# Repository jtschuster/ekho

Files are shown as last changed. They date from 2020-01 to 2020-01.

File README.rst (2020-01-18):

Ekho
====

This repository contains the hardware, firware and tools required to run the Ekho.

This version of the hardware is designed by Jacob Sorber and Arwa Alsubhi from PERSIST Lab at Clemson University. Tools and firmware are adapted from their original design and are significantly upgraded by Abu Bakar and Jackson Schuster from KaMoaMoa Lab at Northwestern University. 

Tool Requirements
-----------------
- GNU Scientific Library (GSL) 
- OpenGL Utility Kit (GLUT)
- g++ and gcc
- Arduino and Teensyduino
- Make
- GNUplot
- EAGLE

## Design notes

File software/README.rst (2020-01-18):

Ekho Software
=============

This directory contains firmwares and tools required to run the Ekho

Sub-Directories
---------------

- ``pc_recorder`` Teensy firmware and a real-time processing code to record IV surfaces while connected to a computer. Includes a real-time plot of the IV curves.
- ``mobile_recorder`` Teensy firmware to record IV surfaces when disconnected from a computer (for recording in the wild), and code to convert the recorded data to useable formats.
- ``pc_emulator`` Computer and teensy code to emulate a recorded IV surface.
- ``tools`` Tools for visualizing and converting binary data to other readable formats.

File Formats
------------

**.raw**
    *Raw* format is what the recorded data is placed into after initial processing. The data is in binary format and can be converted into a text file using the tools in pc_recorder. It has the following format repeated for a number of timestamps:
    
    ``<timestamp, 1 double value> <voltages, 512 long double values> <currents, 512 long double values>``

    The j'th voltage value corresponds to the j'th current value. Together, the 512 (voltage, current) points can be regressed to create an IV curve. 

**.sdr**
    *SDRaw* format is used by mobile_recorder to store recorded data in the SD card in a simpler form compared to ``.raw`` format. This is done because of the optimizations that are made to avoid floating point operatins on Teensy so to make the processing faster on the mobile platform. It has the following format repeated for a number of timestamps:
    
    ``<timestamp, 4 bytes> <raw values, 10 bytes>``

**.ivs** 
    *IV surface* format is used by pc_emulator and is generated after finding a regression on the raw data points. The regression coverts 512 raw data points per IV curve from ``.raw`` file into 65 data points. This makes emulation process faster. Several 65-point IV curves together make an IV surface (``.ivs``). This file is also in unreadable binary format. It has the following format repeated for a number of timestamps:
    
    ``<timestamp, 1 double value> <currents, 65 long double values>``

**.gnu** 
    This is a gnuplot file of the IV surfaces. See gnuplot online documentation for more info.

Usage
-------

- Run ``make clean`` to remove executable from all sub-directories.
- Run ``make`` or ``make all`` to compile and generate execuatables.
- Run ``remake`` to clean, compile and generate execuatables.
- Follow instructions in ``pc_recorder`` to record IV surfaces by connecting Ekho reorder with the PC.
- Follow instructions in ``mobile_recorder`` to record IV surfaces in the wild.
- Follow instructions in ``pc_emulator`` to emulate IV surface by connecting Ekho emulator with the PC.
- Follow instructions in ``tools`` to convert and visualize the data.

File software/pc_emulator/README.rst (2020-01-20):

PC Emulation
============

This directory contains Teensy firmware and tool for emulating IV surfaces.

Sub-Directories
---------------

- ``emulator`` Tool for emulating recorded IV surfaces from ``.ivs`` files.
- ``Teensy_firmware_pc_emulate_revE`` Teensy firmware to emulate IV surfaces.

Usage
-----

To emulate IV surfaces when connected to a PC, you need to follow below steps

#. Connect Ekho emulator board to Teensy 3.6 ``A2 -> VSAMP``, ``GND -> GND``, ``A21 -> DAC``.
#. Ensure the dacamp.dat file in emulate.cpp is the correct map for the emulate board.
#. Flash Teensy 3.6 with ``pc_emulate_revE.ino`` code in ``Teensy_firmware_pc_emulate_revE`` directory, using Arduino-teensy.
#. Place a capacitor between emulator output ``LOAD`` and your load. I use 1 uF. 
#. Although the board has a 470 ohm sense resistor, you might need to remove it and replace it with a resistor that suits your recording. Place the sense resistor between ``LOAD_V+`` and ``AMPOUT`` pins on the emulator.  Also, change the variable ``RESISTANCE`` value in ``emulate.cpp`` to reflect the resistance that you are using.

    How to choose a sense resistor for a certain harvester?
    
    >You need to know what the maximum voltage and current your harvester can produce (by plotting the recorded data). Suppose that your harvester produces maximum 4.15V and maximum 0.00036A current. Subtract maximum voltage of your harvester form the maximum voltage that Ekho recorder can record which is 10.30V and divide the result by the maximum current of your harvester (found by analyzing the output of the recording tools). (10.3-4.15)/0.00036 = 17K resistor.
    
    > Now, you need to see the minimum current Ekho emulator produces based on the value of the sense resistor (17K). First, calculate the minimum voltage that can be produced by Ekho emulator = 3.3(maximum voltage of Teensy)* 3.2(opamp gains of Ekho recorder) /4096 (ADC value of 3.3 voltage) = 0.0025 volts. Second, divide this minimum voltage by the sense resistor= 0.0025V/17K = 0.00000015 Amp. 
    
    > So, the minimum current can be played with using 17K sense resistor is 0.00000015 Amp. If your harvester produce less than that you need to pick another resistor value. 

#. To start emulating, and run following command
    
``./emulate.sh <emulator_port> <path_to_ivs_file>``

#. Make sure emulator is powered by a 12V battery or power supply.

Keep following the output on the terminal

| Note
- Run above command after compiling emulate.cpp. This can be done by compiling it in ``emulator`` directory or in Ekho software directory. 
- The emulation program has a one second delay before beginning emulation.
- Run ``make`` or ``make all`` to compile in any of the above directory of your choice.
- Use ``make clean`` or ``make remake`` if needed.

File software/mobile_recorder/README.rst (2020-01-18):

Mobile Recording
================

This folder contains Teensy firmware for in-wild recording and tools for converting the recorded data into useable formats. The converted data is used to emulate and display IV surfaces on the screen.

Sub-Directories
---------------

- ``converter`` Tool for converting raw data from SD card into ``.raw`` format.
- ``Teensy_firmware_mobile_record_revF`` Teensy firmware to record IV surfaces in the wild.

Usage
-----

To record IV surfaces in the wild, you need to follow below steps

#. Connect Ekho record board to Teensy 3.6.
#. Flash Teensy 3.6 with ``mobile_record_revF.ino`` code in ``Teensy_firmware_mobile_record_revF`` directory, using Arduino-teensy. In the code, change desired recording time by changing the value of ``RecordTime`` variable in miliseconds.
#. Make sure the power switch on Ekho record board is either on teensy to power Ekho record board from teensy, or on battery if you choose to (don't forget to connect a battery) .
#. Insert SD card into teensy and notice the led will be on while IV curves are being recorded and will turn off when the recording is completed. Note each curve needs 5128 bytes. So, make sure that you have enough space on the SD card.
#. Leave the recorder in the environment you want to capture IV surfaces for, and remove the SD  card after desired time.
#. To process the data from the SD card (stored in ``.sdr`` format), connect the SD card to your computer, and run following.
    
``./convert <surface_file_name(output)> <sdr_file_from_sdcard(input)>``

Both raw and regressed IV surfaces will be displayed on the screen.

| Note
- Run above command after compiling ``convert.cpp`` and ``generate_surface.cpp``. This can be done individually by compiling in their respective directories or in ekho software directory at once.
- Run ``make`` or ``make all`` to compile in any of the above directory of your choice.
- Use ``make clean`` or ``make remake`` if needed.

Following files will be generated after running ``convert.sh``

***.ivs**
    Regressed IV surface in unreadable format that can be used for emulation.

***.raw**
    Raw IV surface in unreadable binary format.

***.gnu**
    GNU plot code for plotting regressed IV surface.

***_raw.gnu**
    GNU plot code for plotting the raw(recorded) IV surface.

***_render.png**
    IV surface made up of regressed IV curves.

***_render_raw.png**
    IV surface made up of raw(recorded) IV curves.

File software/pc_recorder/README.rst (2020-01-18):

PC Recording
=============

This directory contains Teensy firmware for recording IV surfaces when connected to a computer and tools for converting the recorded data into useable formats. The converted data is used to emulate and display IV surfaces on the screen.

Sub-Directories
---------------

- ``recorder`` Tool for recording sampled data into ``.raw`` format.
- ``Teensy_firmware_pc_record_revF`` Teensy firmware to record IV surfaces when connected with a PC.

Usage
-----

To record IV surfaces when connected to a PC, you need to follow below steps

#. Connect Ekho record board to Teensy 3.6.
#. Flash Teensy 3.6 with ``pc_record_revF.ino`` code in ``Teensy_firmware_pc_record_revF`` directory, using Arduino-teensy. In the code, change desired recording time by changing the value of ``RecordTime`` variable in miliseconds.
#. Make sure the power switch on Ekho record board is either on teensy to power Ekho record board from teensy, or on battery if you choose to (don't forget to connect a battery) .
#. To start recording, and run following command
    
``./record.sh <output file name> <time in ms> <usb port>``

Both raw and regressed IV surfaces will be displayed on the screen.

| Note
- Run above command after compiling ``record.cpp`` and ``generate_surface.cpp``. This can be done individually by compiling them in their respective directories or in ekho software directory at once.
- Run ``make`` or ``make all`` to compile in any of the above directory of your choice.
- Use ``make clean`` or ``make remake`` if needed.

Following files will be generated after running ``convert.sh``

***.ivs**
    Regressed IV surface in unreadable format that can be used for emulation.

***.raw**
    Raw IV surface in unreadable binary format.

***.gnu**
    GNU plot code for plotting regressed IV surface.

***_raw.gnu**
    GNU plot code for plotting the raw(recorded) IV surface.

***_render.png**
    IV surface made up of regressed IV curves.

***_render_raw.png**
    IV surface made up of raw(recorded) IV curves.

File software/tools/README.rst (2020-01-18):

Ekho Tools
==========

This directory contains Tools for visualizing and converting binary data to other readable formats. The converted data is used to emulate and display IV surfaces on the screen.

Sub-Directories
---------------

- ``generate_surface`` Converts ``.raw`` data file into ``.ivs`` and ``.gnu`` files for visualizing recorded and regressed IV surfaces.
- ``convert_IV_to_txt_file`` Converts an ``.ivs`` file into a ``.txt`` file with format ``<timestamp, voltage, current>``.
- ``convert_rawData_to_txt_file:`` Converts a ``.raw`` file into a ``.txt`` file with format ``<timestamp, voltage, current>``.
- ``dac_mapper``: Generates a DAC map of the op-amps used on the emulator. 
- ``repeat_curve``: Creates a 10 second long IV surface from a specific IV curve in an ``.ivs`` file.

Usage
-----

- Run ``make clean`` to remove executable from all sub-directories.
- Run ``make`` or ``make all`` to compile and generate execuatables.
- Run ``remake`` to clean, compile and generate execuatables.
- Follow instructions in desired directories to proceed.

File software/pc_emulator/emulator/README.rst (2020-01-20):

Emulating IV Surfaces
=====================

This folder contains tool for emulating IV surfaces.

To emulate IV surfaces when connected when connected to a PC, follow below steps

#. Connect Ekho emulator board to Teensy 3.6 ``A2 -> VSAMP``, ``GND -> GND``, ``A21 -> DAC``.
#. Ensure the dacamp.dat file in emulate.cpp is the correct map for the emulate board.
#. Flash Teensy 3.6 with ``pc_emulate_revE.ino`` code in ``Teensy_firmware_pc_emulate_revE`` directory, using Arduino-teensy.
#. Place a capacitor between emulator output ``LOAD`` and your load. I use 2.2 uF. 
#. Although the board has a 470 ohm sense resistor, you might need to remove it and replace it with a resistor that suits your recording. Place the sense resistor between ``LOAD_V+`` and ``AMPOUT`` pins on the emulator.  Also, change the variable ``RESISTANCE`` value in ``emulate.cpp`` to reflect the resistance that you are using.

    How to choose a sense resistor for a certain harvester?
    
    >You need to know what the maximum voltage and current your harvester can produce (by plotting the recorded data). Suppose that your harvester produces maximum 4.15V and maximum 0.00004A current. Subtract maximum voltage of your harvester form the maximum voltage that Ekho recorder can record which is 10.30V and divide the result by the maximum current of your harvester (found by analyzing the output of the recording tools). (10.3-4.15)/0.00004 = 125K resistor.
    
    > Now, you need to see the minimum current Ekho emulator produces based on the value of the sense resistor (125K). First, calculate the minimum voltage that can be produced by Ekho emulator = 3.3(maximum voltage of Teensy)* 3.2(opamp gains of Ekho recorder) /4096 (ADC value of 3.3 voltage) = 0.0025 volts. Second, divide this minimum voltage by the sense resistor= 0.0025V/125K = 0.00000002 Amp. 
    
    > So, the minimum current can be played with using 125K sense resistor is 0.00000002 Amp. If your harvester produce less than that you need to pick another resistor value. 

#. To start emulating, and run following command
    
``./emulate <emulator_port> <path_to_ivs_file>``

#. Make sure emulator is powered by a 12V battery or power supply.
Keep following the output on the terminal

| Note
- Run above command after compiling emulate.cpp. This can be done by compiling it in ``emulator`` directory or in Ekho software directory. 
- The emulation program has a one second delay before beginning emulation.
- Run ``make`` or ``make all`` to compile in any of the above directory of your choice.
- Use ``make clean`` or ``make remake`` if needed.

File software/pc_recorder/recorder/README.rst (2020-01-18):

Recording Real-Time IV Surfaces
===============================

This directory contains the tool for recording real-time IV curves into ``.raw`` format. It also displays a real-time plot of IV data points.

To record the data, follow below steps

#. Connect Teensy (soldered with Ekho record board) to the PC
#. Compile ``record.cpp`` file using ``make`` or ``make all`` 
#. Start recording by entering below command

``./record <output file name> <time in ms> <usb port>``

Use ``make clean`` or ``make remake`` if needed.

Following file(s) will be generated after running ``record``

***.raw**
    Raw IV surface in unreadable binary format.

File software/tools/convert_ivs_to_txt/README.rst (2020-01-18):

Binary to Text
==============

This directory contains the tool for converting ``.ivs`` (binary) data file into a ``.txt`` file with format ``<timestamp, voltage, current>``.

To convert the data, follow below steps

#. Compile ``convert.c`` file using ``make`` or ``make all``.
#. Convert the data using below command.

``./convert <path_to_ivs_file>``

Use ``make clean`` or ``make remake`` if needed.

Following file(s) will be generated after running ``convert``

**IVSData.txt**
    A human readable IV surface with each line representing a point on regressed IV curve.

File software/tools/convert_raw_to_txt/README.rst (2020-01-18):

Binary to Text
==============

This directory contains the tool for converting ``.raw`` (binary) data file into a ``.txt`` file with format ``<timestamp, voltage, current>``.

To convert the data, follow below steps

#. Compile ``convert.c`` file using ``make`` or ``make all``.
#. Convert the data using below command.

``./convert <path_to_raw_file>``

Use ``make clean`` or ``make remake`` if needed.

Following file(s) will be generated after running ``convert``

**rawData.txt**
    A human readable IV surface with each line representing a point on raw IV curve.

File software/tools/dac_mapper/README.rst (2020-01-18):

Generating DAC Map
=================

This directory contains the Teensy firmware for generating DAC map of op-amps used on the emulator. We notice that DAC map varies from hardware to hardware. Generating your own would help in emulating IV curves accurately.

To generate the DAC map, follow below steps

#. Connect Teensy with emulator ``A2 -> VSAMP``, ``GND -> GND``, ``A21 -> DAC``
#. Flash Teensy 3.6 with ``dac_mapper.ino`` code.
#. Make sure emulator is powered by a power supply/battery and not Teensy.
#. Insert SD card into Teensy.
#. Wait till the LED on the teensy goes off which means a text file has been created.
#. Transfer the text file ``dacmap.txt`` from SD card to your computer so you can use it to create the dacmap for your emulator.
#. For each value X in that text file, use the formula X*(3.3/4095)*3.2. So you ended up with 4096 values (you can write a script to do this calculation or use Excel sheet).  
#. Copy 4096 resulted values to replace the values in "dacmap.dat" file in ``dac_mapper`` directory.

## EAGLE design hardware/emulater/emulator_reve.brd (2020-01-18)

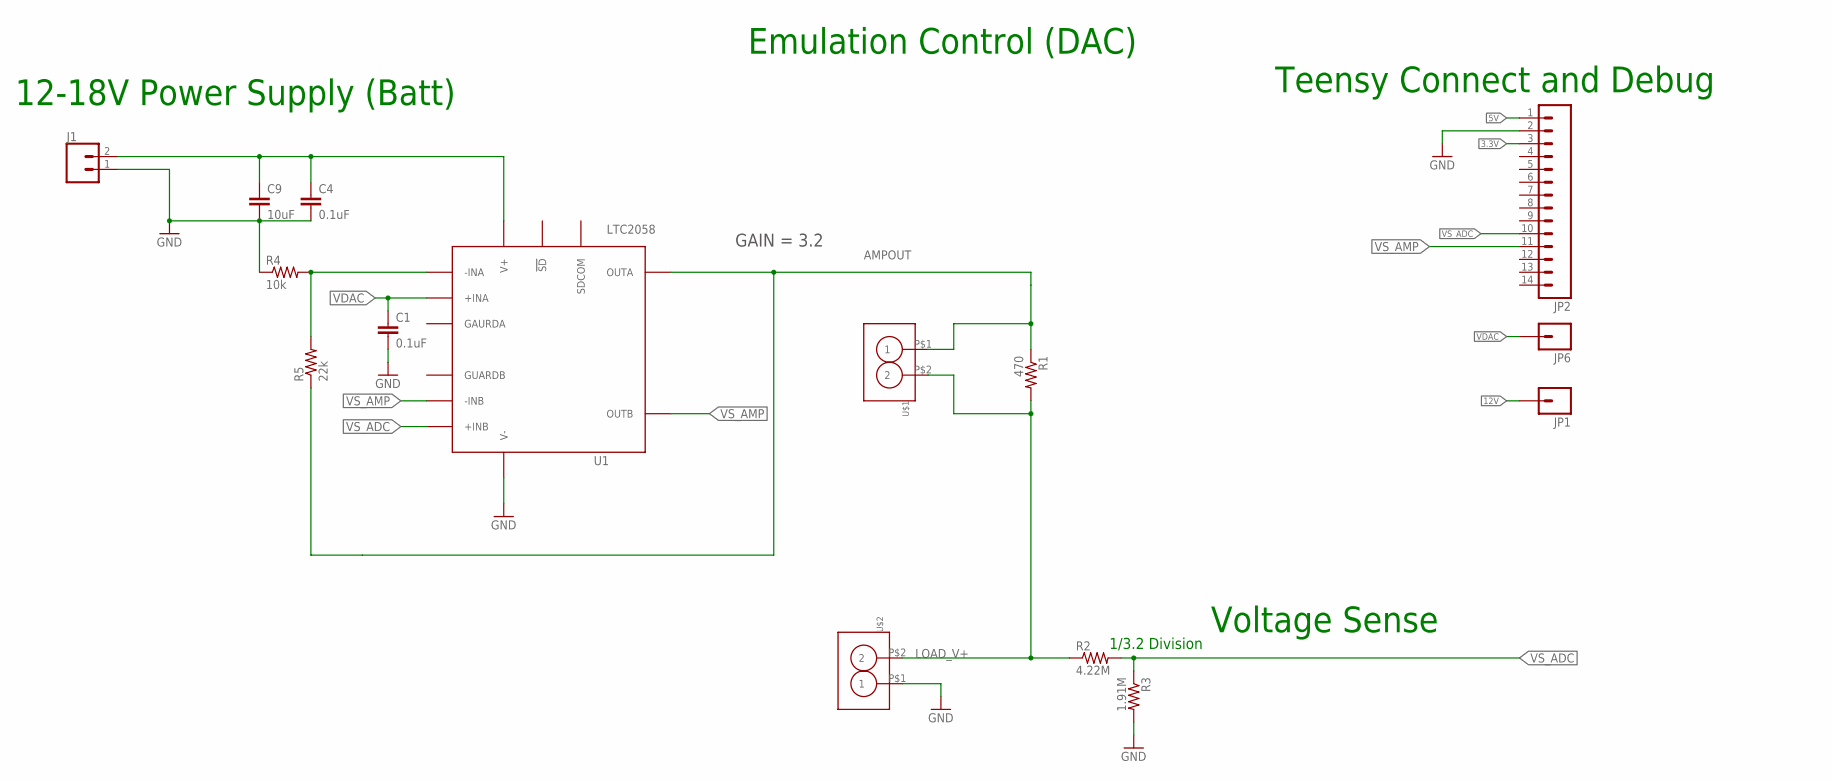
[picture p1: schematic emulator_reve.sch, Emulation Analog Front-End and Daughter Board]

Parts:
C1, C4: 0.1uF; 0603; DIGIKEY 490-3271-1-ND
C9: 10uF; 1210; DIGIKEY 490-1867-1-ND
J1: CONN_02; 1X02
JP1, JP6: M01PTH; 1X01
JP2: M14; 1X14
R1: 470; 0805
R2: 4.22M; 0603; DIGIKEY P2.0MJCT-ND
R3: 1.91M; 0603; DIGIKEY P2.0MJCT-ND
R4: 10k; 0603; DIGIKEY 311-40.2KLRCT-ND
R5: 22k; 0603; DIGIKEY 311-40.2KLRCT-ND
U1: LTC2058; MSOP12
U$1, U$2: SCREW_CONNECTOR-2PIN'; SCREW_CONNECTOR-2PIN-3.5MM

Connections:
3.3V: JP2.3
5V: JP2.1
12V: C4.1, C9.1, J1.2, JP1.1, U1.11 (V+)
AMPOUT: R1.1, R5.1, U1.3 (OUTA), U$1.P$1 (1)
GND: C1.2, C4.2, C9.2, J1.1, JP2.2, R3.2, R4.1, U1.2 (V-), U1.EXP (V-), U$2.P$1 (1)
INA-: R4.2, R5.2, U1.5 (-INA)
LOAD_V+: R1.2, R2.1, U$1.P$2 (2), U$2.P$2 (2)
VDAC: C1.1, JP6.1, U1.6 (+INA)
VS_ADC: JP2.10, R2.2, R3.1, U1.7 (+INB)
VS_AMP: JP2.11, U1.8 (-INB), U1.10 (OUTB)

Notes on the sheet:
Voltage Sense
1/3.2 Division
Emulation Control (DAC)
12-18V Power Supply (Batt)
GAIN = 3.2
Teensy Connect and Debug

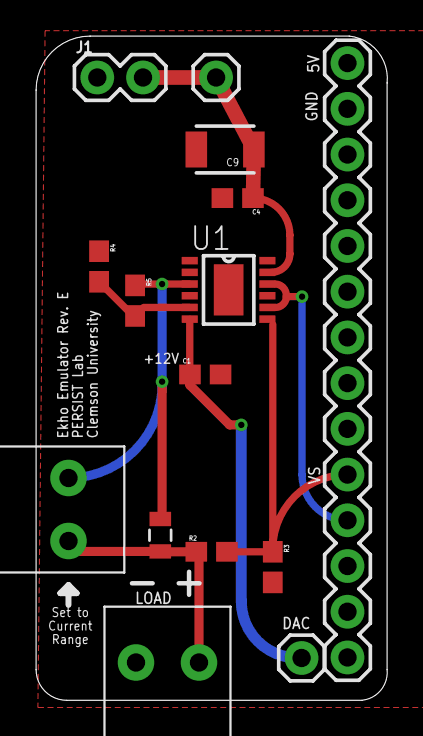
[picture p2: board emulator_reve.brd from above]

Board: 2 copper layers, 19.5 x 36.9 mm, 15 parts (0 on the bottom side), 8 nets.

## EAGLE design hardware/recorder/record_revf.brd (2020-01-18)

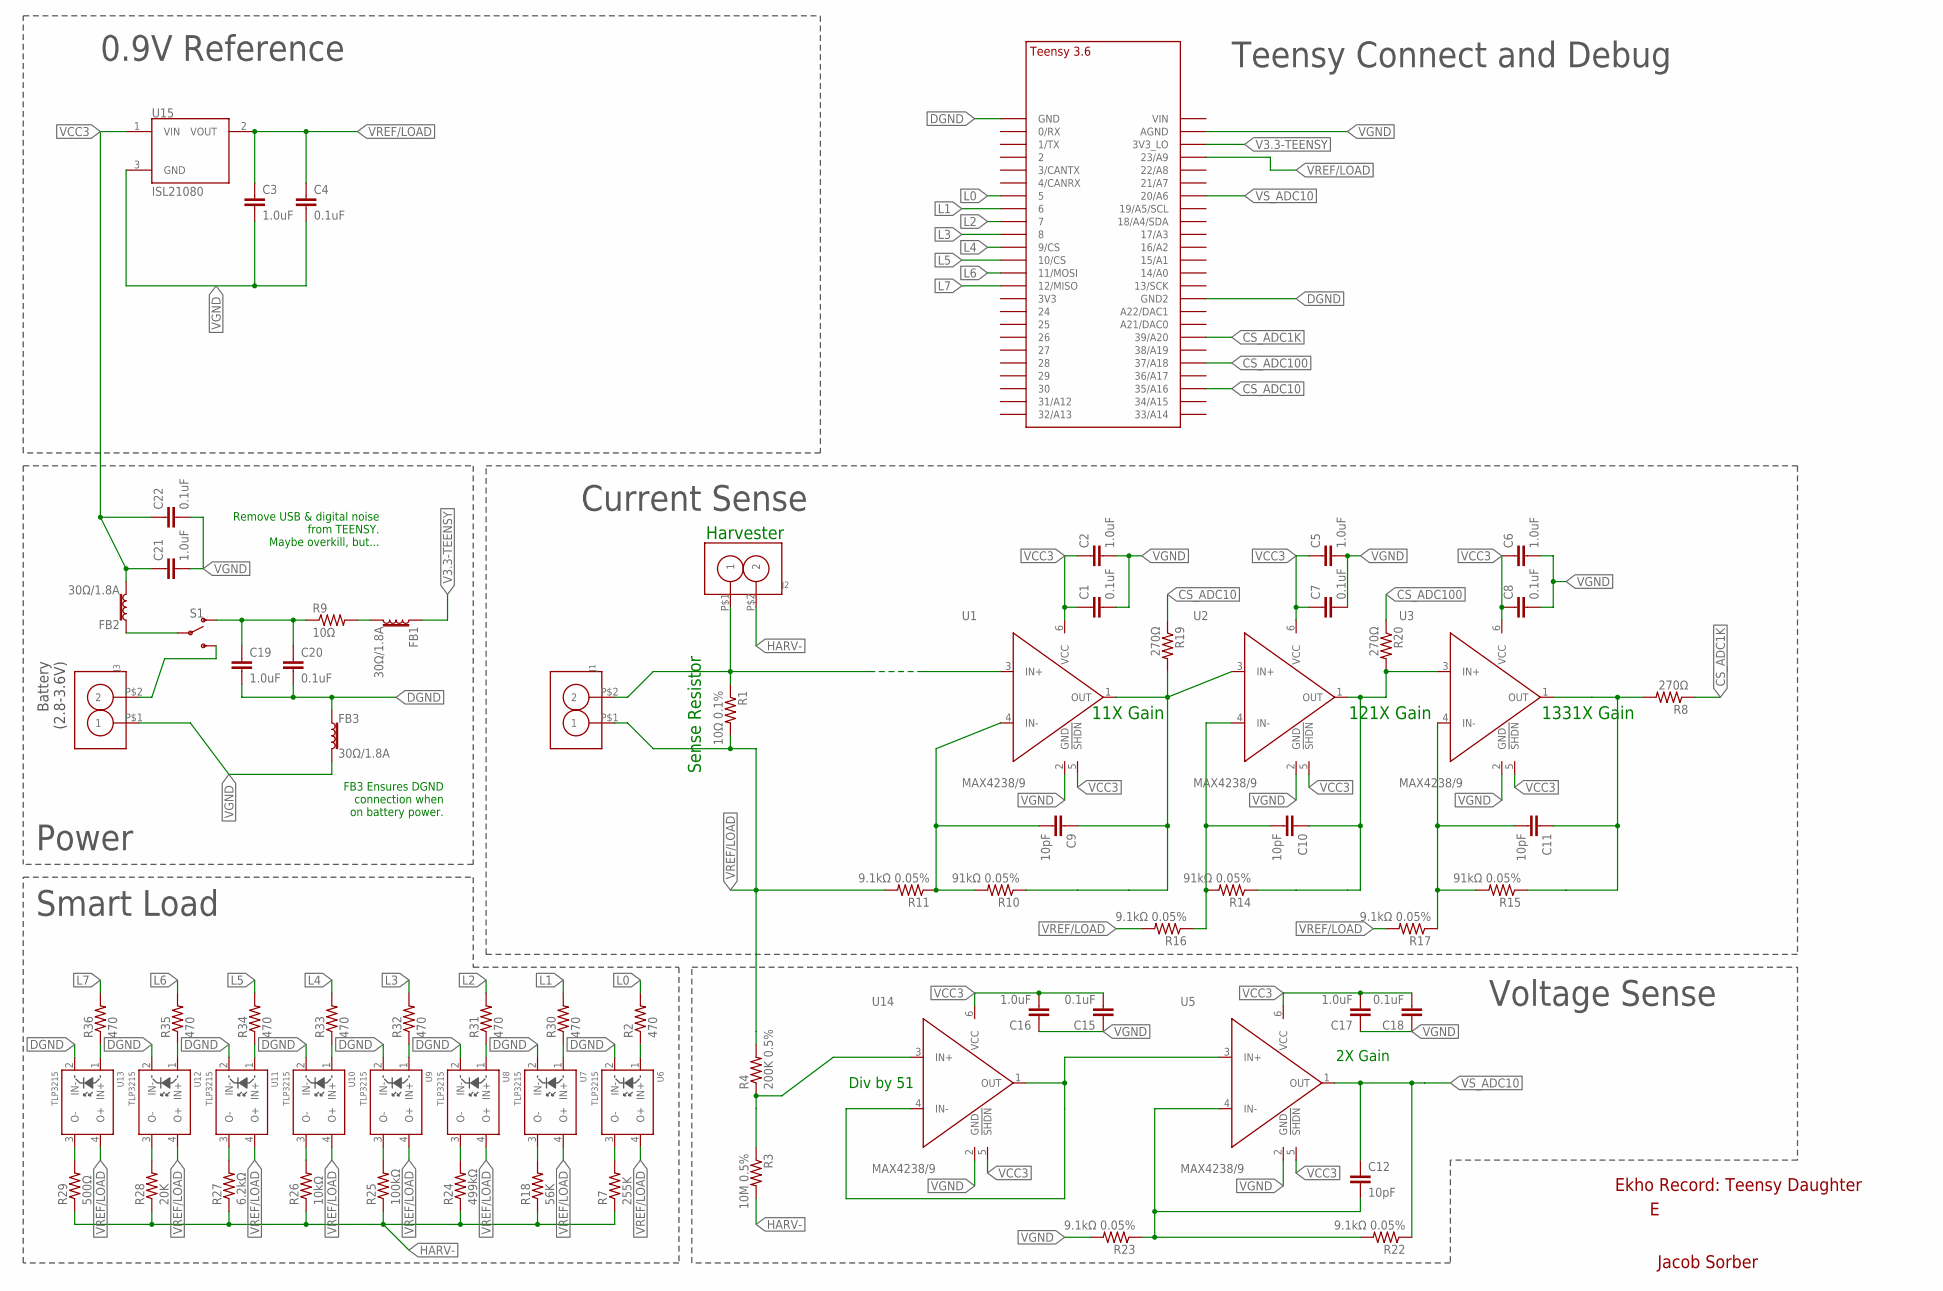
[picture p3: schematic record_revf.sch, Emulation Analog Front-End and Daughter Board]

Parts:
C1, C4, C7, C8, C15, C18, C20, C22: 0.1uF; 0603; DIGIKEY 490-3271-1-ND
C2, C3, C5, C6, C16, C17, C19, C21: 1.0uF; 0603; DIGIKEY 490-3890-1-ND
C9, C10, C11, C12: 10pF; 0603; DIGIKEY 490-3271-1-ND
FB1, FB2, FB3: 30Ω/1.8A; 0603
J1, J2, J3: SCREW_CONNECTOR-2PIN'; SCREW_CONNECTOR-2PIN-3.5MM
R1: 10Ω 0.1%; 0805
R2, R30, R31, R32, R33, R34, R35, R36: 470; 0603; DIGIKEY P2.0MJCT-ND
R3: 10M 0.5%; 0603; DIGIKEY P2.0MJCT-ND
R4: 200K 0.5%; 0603; DIGIKEY P2.0MJCT-ND
R7: 255K; 0603; DIGIKEY P2.0MJCT-ND
R8, R19, R20: 270Ω; 0603; DIGIKEY P2.0MJCT-ND
R9: 10Ω; 0805
R10, R14, R15: 91kΩ 0.05%; 0603; DIGIKEY P2.0MJCT-ND
R11, R16, R17, R22, R23: 9.1kΩ 0.05%; 0603; DIGIKEY P2.0MJCT-ND
R18: 56K; 0603; DIGIKEY P2.0MJCT-ND
R24: 499kΩ; 0603; DIGIKEY P2.0MJCT-ND
R25: 100kΩ; 0603; DIGIKEY P2.0MJCT-ND
R26: 10kΩ; 0603; DIGIKEY P2.0MJCT-ND
R27: 6.2kΩ; 0603; DIGIKEY P2.0MJCT-ND
R28: 20K; 0603; DIGIKEY P2.0MJCT-ND
R29: 500Ω; 0603; DIGIKEY P2.0MJCT-ND
S1: SWITCH-SPDT-PTH-11.6X4.0MM-KIT; SWITCH_SPDT_PTH_11.6X4.0MM_KIT
U1, U2, U3, U5, U14: MAX4238/9; SOT23-6
U6, U7, U8, U9, U10, U11, U12, U13: TLP3215
U15: ISL21080; SOT-23
U$6: TEENSY_3.5/3.6_SIDE_ONLY

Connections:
CS_ADC1K: R8.1, U$6.39/A20
CS_ADC10: R19.1, U$6.35/A16
CS_ADC100: R20.1, U$6.37/A18
DGND: C19.2, C20.2, FB3.1, U6.2 (IN-), U7.2 (IN-), U8.2 (IN-), U9.2 (IN-), U10.2 (IN-), U11.2 (IN-), U12.2 (IN-), U13.2 (IN-), U$6.GND, U$6.GND2
HARV+: J1.P$2 (2), J2.P$1 (1), R1.1, U1.3 (IN+)
HARV-: J2.P$2 (2), R3.2, R7.1, R18.1, R24.1, R25.1, R26.1, R27.1, R28.1, R29.1
L0: R2.2, U$6.5
L1: R30.2, U$6.6
L2: R31.2, U$6.7
L3: R32.2, U$6.8
L4: R33.2, U$6.9/CS
L5: R34.2, U$6.10/CS
L6: R35.2, U$6.11/MOSI
L7: R36.2, U$6.12/MISO
unnamed: C9.2, R10.2, R11.1, U1.4 (IN-)
unnamed: R3.1, R4.1, U14.3 (IN+)
unnamed: U5.3 (IN+), U14.1 (OUT), U14.4 (IN-)
unnamed: C19.1, C20.1, R9.1, S1.1 (O)
unnamed: FB1.2, R9.2
unnamed: R29.2, U13.3 (O-)
unnamed: J3.P$2 (2), S1.3 (S)
unnamed: C12.2, R22.2, R23.1, U5.4 (IN-)
unnamed: FB2.1, S1.2
unnamed: R28.2, U12.3 (O-)
unnamed: R27.2, U11.3 (O-)
unnamed: C10.2, R14.2, R16.1, U2.4 (IN-)
unnamed: C11.2, R15.2, R17.1, U3.4 (IN-)
unnamed: R26.2, U10.3 (O-)
unnamed: R25.2, U9.3 (O-)
unnamed: R24.2, U8.3 (O-)
unnamed: R18.2, U7.3 (O-)
unnamed: R7.2, U6.3 (O-)
unnamed: R2.1, U6.1 (IN+)
unnamed: R30.1, U7.1 (IN+)
unnamed: R31.1, U8.1 (IN+)
unnamed: R32.1, U9.1 (IN+)
unnamed: R33.1, U10.1 (IN+)
unnamed: R34.1, U11.1 (IN+)
unnamed: R35.1, U12.1 (IN+)
unnamed: R36.1, U13.1 (IN+)
OUT1K: C11.1, R8.2, R15.1, U3.1 (OUT)
OUT10: C9.1, R10.1, R19.2, U1.1 (OUT), U2.3 (IN+)
OUT100: C10.1, R14.1, R20.2, U2.1 (OUT), U3.3 (IN+)
V3.3-TEENSY: FB1.1, U$6.3V3_LO
VCC3: C1.1, C2.1, C5.1, C6.1, C7.1, C8.1, C15.2, C16.2, C17.2, C18.2, C21.1, C22.1, FB2.2, U1.5 (!SHDN), U1.6 (VCC), U2.5 (!SHDN), U2.6 (VCC), U3.5 (!SHDN), U3.6 (VCC), U5.5 (!SHDN), U5.6 (VCC), U14.5 (!SHDN), U14.6 (VCC), U15.1 (VIN)
VGND: C1.2, C2.2, C3.2, C4.2, C5.2, C6.2, C7.2, C8.2, C15.1, C16.1, C17.1, C18.1, C21.2, C22.2, FB3.2, J3.P$1 (1), R23.2, U1.2 (GND), U2.2 (GND), U3.2 (GND), U5.2 (GND), U14.2 (GND), U15.3 (GND), U$6.AGND
VREF/LOAD: C3.1, C4.1, J1.P$1 (1), R1.2, R4.2, R11.2, R16.2, R17.2, U6.4 (O+), U7.4 (O+), U8.4 (O+), U9.4 (O+), U10.4 (O+), U11.4 (O+), U12.4 (O+), U13.4 (O+), U15.2 (VOUT), U$6.23/A9
VS_ADC10: C12.1, R22.1, U5.1 (OUT), U$6.20/A6

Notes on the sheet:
Sense Resistor
Voltage Sense
Current Sense
2X Gain
Teensy Connect and Debug
Harvester
Smart Load
Jacob Sorber
Ekho Record: Teensy Daughter
0.9V Reference
11X Gain
121X Gain
1331X Gain
Div by 51
Battery (2.8-3.6V)
FB3 Ensures DGND connection when on battery power.
Remove USB & digital noise from TEENSY. Maybe overkill, but...
Power

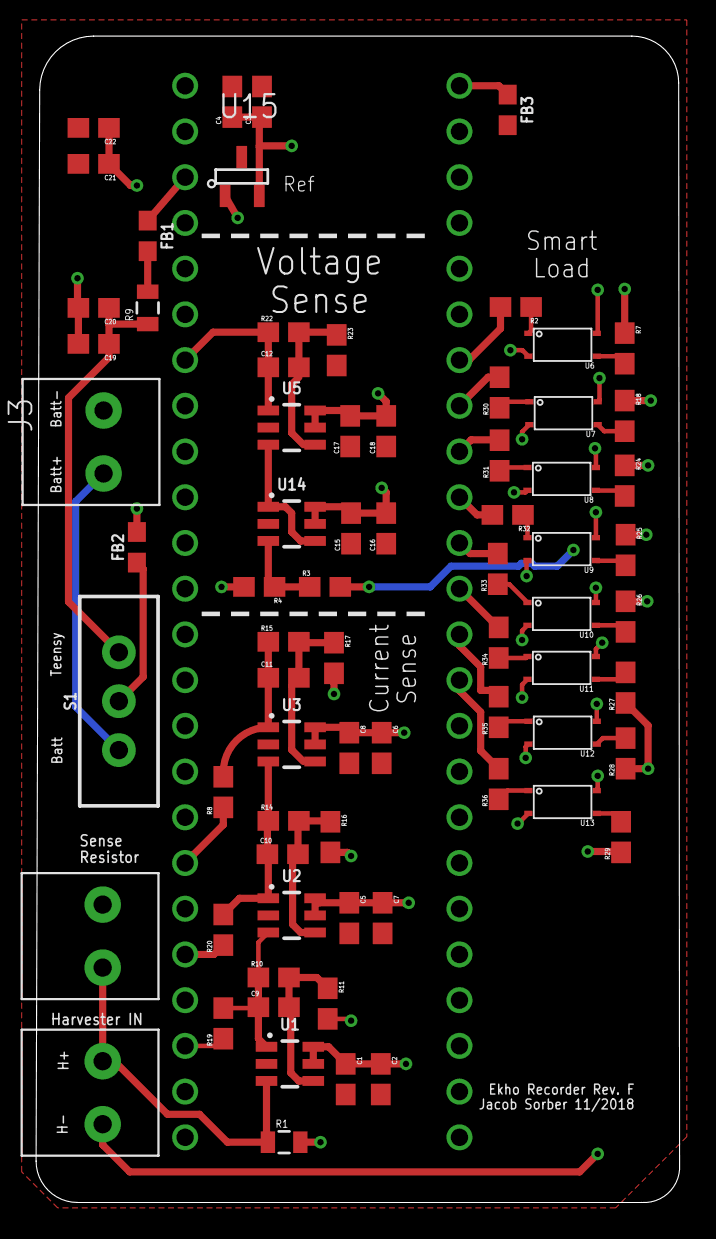
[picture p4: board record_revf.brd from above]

Board: 4 copper layers, 35.8 x 64.8 mm, 73 parts (1 on the bottom side), 48 nets.

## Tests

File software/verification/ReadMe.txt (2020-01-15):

The mse program compares a recorded surface to an emulated surface. This is only for use when a recorder is set up as the load to an emulator. This assumes the recording is longer than the emulation and the emulation begins after the recording has started. 

Usage:
    ./mse <emulated .ivs file> <recorded .ivs file> <time emulation begins>

The program will print the mean square error, percent error, and average deviation for each timestamp and average over all timestamps. The program disregards points on the IV curve where the emulated current is under 1e-8.

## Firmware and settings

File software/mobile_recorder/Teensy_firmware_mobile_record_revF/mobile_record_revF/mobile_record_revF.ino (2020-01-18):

//CREATES RAWDATAx.RAW FOR x=1 though 9

#include <ADC.h> // inculde ADC library
#include <SD.h>
#include <SPI.h>

//#define COUNT 500
#define COUNT 512

const int chipSelect = BUILTIN_SDCARD;
int timerFlage = 0, NumCurve =0;
uint8_t smartLoad_pins[8]={5,6,7,8,9,10,11,12}; // define an array of 8 pins to randomally generate a smart load
ADC *adc = new ADC(); // adc object
uint16_t voltage, current_1,current_2,current_3, Vref;
uint32_t timeStamp;
byte timeStampData[4];
int pointCount = 0 ;
int led = 13;
byte rawData[10];
unsigned long EndTimetMillis;
const long RecordTime = 10000; //10ms, 1800000= 30min, 60000 = 1 min , 600000= 10 mins// change to any valaue that you want in milisecond
 unsigned long StartTimetMillis;
 int StartFlag = 1;
 File dataFile;
 
void setup() {
  Serial.begin(9600);
  pinMode(led, OUTPUT);   
  if (!SD.begin(chipSelect)) 
  {
   // Serial.println("Card failed, or not present");
    // don't do anything more:
    return;
  }

  else{
      digitalWrite(led, HIGH);
      char filename[64];
      for (char i = 0; i<10; i++) {
        strcpy(filename, "rawdata_.sdr");
        filename[7] = i+'0';
        if (! SD.exists(filename)) {
          i=9;
        }
      }
      
      dataFile = SD.open(filename, FILE_WRITE);
      if (!dataFile) {
        digitalWrite(led, LOW);
      }
  }
  
  pinMode(5,OUTPUT);
  pinMode(6,OUTPUT);
  pinMode(7,OUTPUT);
  pinMode(8,OUTPUT);
  pinMode(9,OUTPUT);
  pinMode(10,OUTPUT);
  pinMode(11,OUTPUT);
  pinMode(12,OUTPUT);
 
  //Teensy has two ADC modules ADC0 and ADC1, So we need to congigure both modules since ADC pins use them.
  ////// ADC0 module/////
  adc->setAveraging(1, ADC_0); // set number of averages
  adc->setResolution(12, ADC_0); // set 12 bits of resolution for ADC0 module
  adc->setConversionSpeed(ADC_CONVERSION_SPEED::HIGH_SPEED,ADC_0); // change the conversion speed 
  adc->setSamplingSpeed(ADC_SAMPLING_SPEED::HIGH_SPEED,ADC_0); // change the sampling speed
  
//  //////ADC1 module////////////////
  adc->setAveraging(1, ADC_1);
  adc->setResolution(12, ADC_1); // set 12 bits of resolution for ADC1 module
  adc->setConversionSpeed(ADC_CONVERSION_SPEED::HIGH_SPEED,ADC_1 ); // change the conversion speed 
  adc->setSamplingSpeed(ADC_SAMPLING_SPEED::HIGH_SPEED,ADC_1 ); // change the sampling speed

 
}

void loop() {

for (int i=0; i<=255;i++)
{ 
set_smart_Load(i); // set the load by sending a random number from the range [0-255] to a "set_smart_Load" function, where 255 = maximum value can be represent by 8 bits

delayMicroseconds(550);        // pauses for 550 microseconds (swichs for smart load need max 500us to be on or off)
//////  // Get IV point

  current_3 = adc->analogRead(A20); // read a new value, will return ADC_ERROR_VALUE if the comparison is false.
  current_2 = adc->analogRead(A18); // read a new value, will return ADC_ERROR_VALUE if the comparison is false.
  current_1 = adc->analogRead(A16); 
  voltage = adc->analogRead(A6);
  Vref = adc->analogRead(A9);
  
  rawData[0] = (byte) current_1 & 0xff;
  rawData[1] = (byte) (current_1 >> 8) & 0xff;
  rawData[2] = (byte) current_2 & 0xff;
  rawData[3] = (byte) (current_2 >> 8) & 0xff;
  rawData[4] = (byte) current_3 & 0xff;
  rawData[5] = (byte) (current_3 >> 8) & 0xff;
  rawData[6] = (byte) voltage & 0xff;
  rawData[7] = (byte) (voltage >> 8) & 0xff;   
  rawData[8] = (byte) Vref & 0xff;
  rawData[9] = (byte) (Vref >> 8) & 0xff;  
  
  if (dataFile) 
  {
    if (StartFlag == 1)
    {
      StartTimetMillis = millis();
      StartFlag =0;
    }
  if (pointCount == 0)
     {
      timeStamp =  millis(); //record the start time of each curve
      timeStampData[3] = (byte) (( timeStamp & 0xFF000000) >> 24 );
      timeStampData[2] = (byte) (( timeStamp & 0x00FF0000) >> 16 );
      timeStampData[1] = (byte) (( timeStamp & 0x0000FF00) >> 8  );
      timeStampData[0] = (byte) (( timeStamp & 0X000000FF)       );
      dataFile.write(timeStampData, 4);
    }
    if (pointCount == COUNT * 10 - 10)
  {
       EndTimetMillis =  millis();
      timeStampData[3] = (byte) (( EndTimetMillis & 0xFF000000) >> 24 );
      timeStampData[2] = (byte) (( EndTimetMillis & 0x00FF0000) >> 16 );
      timeStampData[1] = (byte) (( EndTimetMillis & 0x0000FF00) >> 8  );
      timeStampData[0] = (byte) (( EndTimetMillis & 0X000000FF)       );
      dataFile.write(timeStampData, 4);

  }

    
    pointCount += dataFile.write(rawData, 10);
    
  } 
  
  if (pointCount == COUNT * 10)
  {
    EndTimetMillis =  millis();
    pointCount = 0;
    NumCurve++;
     if (EndTimetMillis-StartTimetMillis >= RecordTime)
     {
          
        dataFile.close();
        digitalWrite(led, LOW);
//        Serial.print("Number of recorded curve = ");
//         Serial.print(NumCurve);
//          Serial.print("\n");
//          Serial.print("StartTimetMillis = ");
//          Serial.print(StartTimetMillis);
//           Serial.print("\n");
//           Serial.print("EndTimetMillis = ");
//           Serial.print(EndTimetMillis);
//         Serial.print("\n");
//          Serial.print(EndTimetMillis-StartTimetMillis);
        exit(0); // stop the program
      }
  }

}
}

void set_smart_Load(uint8_t value) 
{ 
  
  for (byte i=0; i<8; i++) { // loop through 8 bits of recived value. check if it is one , drives the corresponding pin high. if it is 0 drives the corresponding pin low.
    byte state = bitRead(value, i);
    digitalWrite(smartLoad_pins[i], state);
  }
  
} 

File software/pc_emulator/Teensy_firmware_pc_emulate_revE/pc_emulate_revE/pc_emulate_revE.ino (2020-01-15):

#include <ADC.h>

//#define COUNT 500
#define COUNT 512

ADC *adc = new ADC();
uint16_t current_curve[65];
const int statPin=2;
uint16_t voltage=0;
unsigned char buf[512];
uint16_t bcount = 0;
uint16_t i = 0;
byte response[2];
uint16_t interpolate_f(uint16_t _adc_14_value, uint16_t _shift_bits) 

{ //shifted by 6 why?
  // after getting the voltage value (Vs) shift it by 6 to get the integer value from the [0-64] range. 
  //2^6 = 64 which is the number of points on x axis (voltage) on IV curve. 
	uint16_t left = _adc_14_value >> _shift_bits;
	return	current_curve[left] -
				((
					(uint32_t)(current_curve[left] - current_curve[left+1]) * 
					(uint32_t)(_adc_14_value - (left << _shift_bits))
				) >> _shift_bits);
};

void setup() {
	pinMode(A2, INPUT); // VS_AMP
	pinMode(statPin, OUTPUT);//for debugging
  pinMode(A21, OUTPUT);


////// config ADC0 /////
  adc->setAveraging(1, ADC_0); // set number of averages
  adc->setResolution(12, ADC_0); // set bits of resolution
  adc->setConversionSpeed(ADC_CONVERSION_SPEED::HIGH_SPEED, ADC_0); // change the conversion speed
  adc->setSamplingSpeed(ADC_SAMPLING_SPEED::HIGH_SPEED, ADC_0); // change the sampling speed

	// 12-bit DAC
	analogWriteResolution(12); 

	delay(2000);
}

void loop() {
	// Calculate output value (TODO: dont use float math, use a table)
	voltage = adc->analogRead(A2,ADC_0);
	// Start reading in a new curve if necessary
 
	while(Serial.available()) {
		if(bcount == 0) {
			digitalWrite(statPin, LOW);
		}
		buf[bcount++] = Serial.read();
		if(bcount > 129) {
			digitalWrite(statPin, HIGH);
                        
			for(i=0;i<130;i+=2) {
				current_curve[i / 2] = (buf[i+1] << 8) + buf[i]; // Teensy3.6 is a big endian
			}
			bcount = 0; 
			break;
		}
	}

    
	// Write to DAC
 analogWrite(A21, interpolate_f(voltage,6));
 
}

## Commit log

2019-12-19 Testing complete. Documentation in progress
    [DACMap2.csv, DACMap2.xlsx, DAC_map.csv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]
2020-01-16 changed files names
    [DACMap2.csv, DACMap2.xlsx, DAC_map.csv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]
2020-01-16 removed unnecessary damap files
    [DACMap2.csv, DACMap2.xlsx, DAC_map.csv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]
2020-01-17 adding hardware files
    [emulator_reve.brd, emulator_reve.sch, record_revf.brd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]
2020-01-20 added where resistor goes on the emulate board

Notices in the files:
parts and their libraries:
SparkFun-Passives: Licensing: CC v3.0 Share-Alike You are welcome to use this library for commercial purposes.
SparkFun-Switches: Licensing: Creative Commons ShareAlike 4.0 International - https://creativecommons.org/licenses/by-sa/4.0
